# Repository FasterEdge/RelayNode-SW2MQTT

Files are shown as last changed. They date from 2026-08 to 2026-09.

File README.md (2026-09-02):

<div align="center">
  
  <h2>RelayNode-SW2MQTT</h2>
  <h3>四路隔离开关输入转 MQTT 节点</h3>
</div>

### 一、项目简介

- **用途**: 将四路干接点或开关输入转换为 Wi-Fi MQTT 状态消息，适用于边缘设备和工业开关量接入。
- **硬件工程**: `hardware/sw2mqtt_main.eprj2` 为嘉立创 EDA 专业版工程，`BOM.md` 与 `BOM.txt` 提供物料信息。
- **固件位置**: `firmware/ESP8266/platformio_ide/` 包含 ESP-12F 的 PlatformIO Arduino 固件；`firmware/README.md` 提供固件操作说明。

### 二、硬件设计

- **主控与网络**: 使用 ESP8266 ESP-12F Wi-Fi 模组。
- **输入接口**: 四路输入通过 PC817 光耦隔离，分别连接 GPIO14、GPIO12、GPIO13 和 GPIO4；光耦集电极侧使用 10KΩ 上拉。
- **USB 与烧录**: 板载 CH340X USB-UART 和 USB-C 接口，用于供电、串口烧录及调试。
- **电源**: USB-C 5V 经 AMS1117-3.3 转换为 3.3V；板载红色电源指示灯。
- **控制与状态**: SW1 将 RST 接地实现复位；GPIO2 驱动低电平有效的蓝色状态灯。
- **PCB 状态**: BOM 文档记录该设计为约 83.8 × 48.0 mm 的双层板，34 个元件、126 个焊盘和 29 个网络，最终 PCB DRC 为 0 错误、0 警告。

### 三、固件功能

- **输入采集**: 输入为低电平有效，默认防抖时间为 30 ms；状态变化后发布对应的 `0` 或 `1`。
- **设备标识**: 设备 ID 使用 `sw2mqtt-<chip-id>`，主题基路径为 `<FE_MQTT_TOPIC_PREFIX>/<device-id>`。
- **输入主题**: `input/1` 至 `input/4` 发布开关状态，并由 `FE_MQTT_RETAIN_INPUTS` 控制保留消息。
- **可用性主题**: `availability` 使用保留的 `online` / `offline` 消息，其中 `offline` 由 MQTT LWT 提供。
- **心跳主题**: `state` 周期发布包含运行时间、Wi-Fi RSSI 和 IP 地址的 JSON 心跳，模板默认周期为 60 秒。
- **连接维护**: Wi-Fi 未连接时每 15 秒重试，MQTT 未连接时每 5 秒重试；MQTT 连接成功时状态灯常亮，断开时闪烁。

### 四、配置与构建

- **构建环境**: PlatformIO 默认环境为 `esp12f`，使用 `espressif8266` 平台、`esp12e` 板级配置和 Arduino 框架。
- **依赖**: MQTT 客户端使用 `knolleary/PubSubClient@^2.8`，并启用 Arduino lwIP2 低内存构建标志。
- **串口参数**: 监视器波特率为 115200，上传速率为 460800。
- **配置文件**: 以 `include/config.example.h` 为模板配置 Wi-Fi、MQTT、主题前缀、防抖和心跳参数；不得提交真实密钥或生产凭据。

```bash
cd firmware/ESP8266/platformio_ide
pio run
pio run -t upload
pio device monitor
```

- **首次烧录**: 如开发板不能自动控制启动模式，按住 GPIO0 为低电平、触发 RESET 后再释放 GPIO0，手动进入 ESP8266 bootloader。

### 五、目录说明

- **`hardware/sw2mqtt_main.eprj2`**: 嘉立创 EDA 专业版硬件工程。
- **`BOM.md` / `BOM.txt`**: 物料、网络连接和生产验证信息。
- **`firmware/README.md`**: 固件功能、主题和烧录步骤。
- **`firmware/ESP8266/platformio_ide/`**: PlatformIO 工程、配置模板和 ESP8266 源码。

### 六、许可证

- **许可协议**: 根目录 `LICENSE` 为 Apache License 2.0。
- **凭据提醒**: 许可证不改变部署凭据的保密要求；发布、共享或提交前应确认配置中不包含真实 Wi-Fi 或 MQTT 密钥。

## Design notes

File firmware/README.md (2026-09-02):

# RelayNode-SW2MQTT firmware

## Directory

- `ESP8266/platformio_ide/`: ESP-12F firmware for VS Code + PlatformIO, Arduino framework.

## Features

- Reads the four optocoupler outputs on GPIO14, GPIO12, GPIO13 and GPIO4.
- Active-low input interpretation and 30 ms debounce.
- Publishes each state to MQTT using retained `0`/`1` payloads.
- MQTT availability/LWT (`online`/`offline`) and periodic JSON heartbeat.
- Uses the onboard GPIO2 status LED: on while MQTT is connected, blinking otherwise.

## Configure, build and flash

1. Edit `ESP8266/platformio_ide/include/config.h` with Wi-Fi and MQTT values. `config.example.h` is the template.
2. Connect USB-C. The onboard CH340X provides the serial flashing connection.
3. Put ESP8266 into bootloader mode if required by the board: hold GPIO0 low, pulse RESET, then release GPIO0.
4. Run:

```bash
cd ESP8266/platformio_ide
pio run
pio run -t upload
pio device monitor
```

MQTT topics use `<FE_MQTT_TOPIC_PREFIX>/<chip-id>/`:

- `availability`: `online`/`offline`
- `input/1` ... `input/4`: retained `0` or `1`
- `state`: heartbeat JSON containing uptime, RSSI and IP

> The hardware currently exposes RESET but may not provide automatic DTR/RTS boot control. Manual GPIO0 boot mode can therefore be necessary for the first flash.

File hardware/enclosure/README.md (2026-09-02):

# RelayNode-SW2MQTT 外壳

3D 打印外壳，覆盖 `sw2mqtt_main` PCB（83.8 × 48.0 mm）。

> 来源：嘉立创 EDA 工程 `sw2mqtt_main.eprj2` 实测板框（3300 × 1890 mil）。
> 风格：方形盒式上下盖，USB-C 从短边出线，JP1 排针从顶板穿出。
> 主要特点：**容纳 ESP-12F 模组（16 mm 高）的较高外壳（总高 ~24 mm）**。

## 目录结构

```
enclosure/
├── blender/                  # Blender 源文件
│   ├── enclosure.blend       # 主文件, PCB+34 元件占位 + 上下盖
│   └── enclosure.blend1      # Blender 自动生成
├── stl/
│   ├── top.stl               # 上盖 STL (748 三角面, 37 KB)
│   └── bottom.stl            # 底座 STL (340 三角面, 17 KB)
├── _shot_full.png             # Blender 视图截图(全场景)
├── _shot_shell.png           # 仅外壳视图截图
└── README.md
```

## 几何参数

### 整体

| 维度 | 数值 |
|---|---|
| 外尺寸（X×Y×Z） | 89.8 × 54.0 × 24.0 mm |
| 壁厚 | 2.0 mm |
| 板尺寸 | 83.8 × 48.0 mm（双层板，1.6 mm 厚） |
| 板上空间（内腔高度） | 20.2 mm（容纳 ESP-12F 模组） |
| 板下间隙 | 1.3 mm |

### 上盖（`top.stl`）

- **USB-C 通孔**：7.0 × 4.6 mm，位于 -X 短边壁（对准 J1 @ x=−36.3, y=−10.0）
  - y 范围 −13.5 至 −6.5（宽 7 mm，对准 J1 y=−10.0 中心）
  - z 范围 0.8 至 5.4（贯穿短边壁厚）—— Type-C 头从短边壁底部 4.6 mm 高开口露出
  - 短边壁只保留顶部 2 mm（z 5.4–7.4）作结构件
- **JP1 排针长槽**：x[29.0, 33.0]（宽 **4.0 mm**），y[−8.0, 13.0]（长 21 mm，覆盖 8 针 @ 2.54 mm 间距），z 贯穿整个上盖高度（0.8 → 23.0）让立式排针（高 5 mm）露在空腔内
- **SW1 复位键**：顶板开 6 × 6 mm 孔，内加**按压延长杆**（3 × 3 × 18.4 mm，x[−11.2,−8.2] y[−18.9,−15.9]，从按键顶 z=5.3 延伸到壳外 z=23.7 凸出 0.7 mm）——可从顶部直接按压复位
- **4 处卡扣凸耳**：+Y/−Y 外壁（y=±27.0）内侧 z 0.4–0.7 局部内凸 0.4 mm

### 底座（`bottom.stl`）

- 开口朝上，PCB 嵌入槽 85.8 × 50.0 × 1.3 mm（板 + 1 mm 单边间隙）
- **4 处滑动凹槽**：+Y/−Y 外壁（y=±27.0）内侧 z 0.4–0.8 局部内凹 0.4 mm，与上盖凸耳配合（y=±26.6–27.0 完全嵌合）

### 卡扣原理

滑动卡扣（snap-fit）：上盖从顶部压下，**凸耳（y=±26.6–27.0 内凸）沿底座凹槽（y=±26.6–27.0 内凹）滑入嵌合**，靠材料弹性 + 0.4 mm 过盈摩擦固定。

> **暗病修复记录（2025-02）**：
> 1. 卡扣位置错误（原放在 y=±10，而本壳外壁在 y=±27，卡扣悬浮在内腔且可能顶到 PCB）→ 已移到外壁 y=±26.6–27.0；
> 2. 凸耳方向错误（外凸与凹槽内凹方向相反无法嵌合）→ 已改为内凸同向嵌合；
> 3. SW1 复位键顶板孔原距按键 15.7 mm 无法按压 → 已加按压延长杆至壳外 0.7 mm；
> 4. JP1 槽原宽 2.6 mm 过窄 → 加宽至 4.0 mm。

## 元件位置（Blender 单位 mm，板中心 = 原点）

| 代号 | 名称 | 位置 (x, y) | 高度 (mm) | 外壳开孔 |
|---|---|---|---|---|
| U1 | ESP-12F 模组 | (−5.8, −2.7) | 16 | 无（内腔容纳） |
| J1 | USB-C 16P | (−36.3, −10.0) | 3.2 | 短边壁通孔 |
| JP1 | 1×8 排针立式 | (+31.0, +2.7) | 5.0 | 顶板长槽 |
| SW1 | 复位按键 | (−9.7, −16.4) | 4.5 | 顶板 6×6 mm 孔 |
| U2 | CH340X MSOP-10 | (−23.6, −10.0) | 1.0 | 无 |
| U3 | AMS1117-3.3 | (−24.9, −9.0) | 1.6 | 无 |
| U4-U7 | PC817×4 光耦 | (+17.0, −12.6 / −2.4 / +7.8 / +17.9) | 4.0 | 无 |
| R1-R16, C1-C6, D1, D2 | 0603 被动元件 | — | 0.6 | 无 |

## 打印参数建议

| 参数 | 数值 |
|---|---|
| 材料 | PLA / PETG |
| 层高 | 0.2 mm |
| 壁（Wall） | ≥ 2 条（0.4 mm 喷嘴）或 4 条（0.8 mm） |
| 填充（Infill） | 20 % |
| 顶/底层（Top/Bottom） | ≥ 4 层 |
| 支撑 | 仅外壳 **不需要**支撑（顶面朝上/底面朝上打印，悬垂面已被验证不存在） |
| 打印方向 | 上盖**顶面朝上**；底座**顶面（开口）朝上** |
| 水平扩展（Horizontal Expansion） | −0.05 mm（凹槽配合更顺滑） |

## 关键设计验证

| 检查项 | 结果 |
|---|---|
| 上下盖 mesh 水密（非流形 / 边界） | ✅ 0 / 0 |
| USB-C 通孔位置对准 J1 | ✅ |
| JP1 长槽覆盖 8 针位 | ✅ |
| SW1 复位键孔对准 SW1 + 延长杆 | ✅ 杆凸出顶面 0.7 mm 可按压 |
| ESP-12F 顶部 (z=16.8) vs 内腔顶 (z=21.0) | ✅ 余量 4.2 mm |
| 元件最高点（ESP 16.8）vs 内腔顶（21.0） | ✅ 余量 4.2 mm |
| STL 文件有效（头校验通过） | ✅ bottom 340 三角 / top 748 三角 |

## 嘉立创 EDA 协作工作流

```
Blender x = (jlc_x_mil − 1730) × 0.0254
Blender y = −(jlc_y_mil − 1505) × 0.0254
Blender z = 0.8 + ½ × 元件高度（板上表面参考）
```

板中心对齐原点（0, 0, 0），X 轴为板长方向（83.8 mm），USB-C 在 -X 短边。

如需从 EDA 重新同步 PCB 元件位置，编辑 `enclosure.blend` 中 `PCB_Reference` 集合的子对象尺寸/位置即可。

## 后续可优化项

- [ ] 加 PCB 定位柱（底部 2 定位销防止板晃动）
- [ ] LED D1（红）/ D2（蓝）位置在顶板或侧壁开小透光孔
- [ ] JP1 顶板外加可拆卸挡板（防尘）
- [ ] 顶部丝印（项目名 / 版本）

---

维护：硬件外壳与 PCB 同步更新。任何 PCB 修改后应重新核对 STL 关键尺寸（板框、端子位置、USB-C 位置、ESP 高度）。

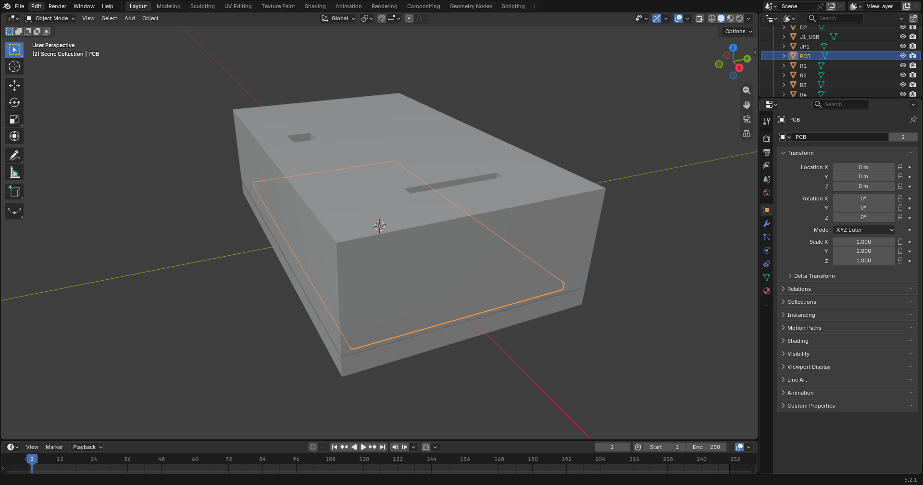
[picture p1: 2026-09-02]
hardware/enclosure/_shot_full.png

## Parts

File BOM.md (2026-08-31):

# RelayNode - SW2MQTT BOM

**开关转 MQTT 信号转换卡**（Switch → MQTT converter）· 嘉立创 EDA 专业版

## 设计要点

- 主控 **ESP8266 ESP-12F**（WiFi，FasterEdge MCU-ESP8266 固件，MQTTAbility）
- **4 路干接点/开关输入**，光耦 PC817 隔离
- 板载 **CH340X** USB-UART，USB-C 直插烧录/调试
- AMS1117-3.3 LDO，USB-C 5V → 3.3V
- D1 红色电源指示灯（3V3）、D2 蓝色状态指示灯（IO2）
- SW1 复位按键（RST↔GND），EN/IO0 上拉、IO15 下拉

## BOM 明细（LCSC 料号，最终确认）

| # | 位号 | 器件 | 型号 | LCSC | 数量 | 封装 |
|---|---|---|---|---|---|---|
| 1 | U1 | WiFi 模组 | ESP-12F | C19949064 | 1 | 模组 16×24mm |
| 2 | U2 | USB-UART | CH340X | C3035748 | 1 | MSOP-10 |
| 3 | U3 | LDO | AMS1117-3.3 | C6186 | 1 | SOT-223 |
| 4 | U4-U7 | 光耦 | PC817X1NSZ0F | C9900007695 | 4 | DIP-4 |
| 5 | J1 | USB-C 母座（16P 含 D+/D-） | TYPE-C-31-M-12 | C165948 | 1 | TYPE-C-SMD |
| 6 | JP1 | 开关输入端子 | 排母 1×8 2.54mm | C9900015386 | 1 | HDR-TH 2.54 |
| 7 | SW1 | 复位按键 | 轻触 2 脚 | C71845 | 1 | THT |
| 8 | D1 | LED 红色 | 0603 红色 | C9900005314 | 1 | 0603 |
| 9 | D2 | LED 蓝色（状态灯 IO2） | 0603 蓝色 | C9900013126 | 1 | 0603 |
| 10 | R1-R4,R11-R14 | 电阻 10KΩ（上拉/配置） | 0603WAF1002T5E | C25804 | 8 | 0603 |
| 11 | R5,R6 | 电阻 470Ω（LED 限流） | 0603WAF4700T5E | C23179 | 2 | 0603 |
| 12 | R7-R10 | 电阻 1KΩ（光耦阳极限流） | 0603WAF1001T5E | C21190 | 4 | 0603 |
| 13 | R15,R16 | 电阻 5.1KΩ（USB-C CC 下拉） | 0603WAF5101T5E | C23186 | 2 | 0603 |
| 14 | C1 | 电容 10µF（5V 输入） | CL10A106KP8NNNC | C19702 | 1 | 0603 |
| 15 | C2-C6 | 电容 100nF（去耦） | CC0603KRX7R9BB104 | C14663 | 5 | 0603 |

## 网络连接概要

- **电源**：J1(5V) → C1/C3 → U3(AMS1117-3.3) → 3V3 → U1/U2/C2/C4/C5
- **烧录**：J1 DP/DN → U2(UD+/UD-) → U2 TXD/RXD → U1 RXD/TXD（交叉）
- **开关输入**：JP1 IN1-4 → PC817 阴极；阳极经 1K→3V3；集电极 10K 上拉→U1 IO14/12/13/4
- **配置**：EN/IO0 上拉 10K，IO15 下拉 10K，RST↔SW1↔GND

## 生产与验证状态

- 原理图：34 个元件，普通模式 DRC 通过；严格模式会因桥 API 无法读取库引脚元数据而返回 false，不影响已生成且一致的 PCB 网表。
- PCB：34 个元件、126 个焊盘、29 个网络，29/29 网络已布通。
- 最终 PCB DRC：0 错误、0 警告；20mil 元件间距检查 561 对，0 违规。
- 布线：289 条走线，统一 10mil；20 个过孔；顶层和底层各 1 个 GND 铺铜。
- 板框约 3300×1890mil（约 83.8×48.0mm），2 层板。
- 丝印位号由 PCB Attribute 图元承载（顶层丝印层 3，共 103 项）；MCP 的 `pcb_get_silkscreens` 只统计 PrimitiveString，因此会误报 0。
- 设计健康报告中的“29 个载流警告”是 MCP 宽度统计缺陷：报告错误读取为 0mil；直接读取 PCB 图元已确认全部 289 条走线均为 10mil，且 GND 有双层铺铜。

## 备注

- 电阻阻值均按实际器件核对（10K=0603WAF1002T5E，470Ω=0603WAF4700T5E，1K=0603WAF1001T5E，5.1K=0603WAF5101T5E），避免早期误选的 5.1Ω/4.7K 错误。
- 光耦用于开关输入隔离，适合工业干接点场景。
- 工程中的生产板为 **Board1（Schematic1 + PCB1）**；`Legacy_Empty_DoNotUse` 是 EDA 自动生成的空原理图占位板，不用于生产，也不要删除，以免触发文档级联操作。

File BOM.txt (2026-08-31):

RelayNode - SW2MQTT BOM（以当前嘉立创 EDA 工程为准）

项目功能：ESP8266 四路隔离开关输入 → MQTT；USB-C 供电与 CH340X 串口烧录
默认装配：全部器件安装

序号	位号	数量	类别/用途	参数或型号	制造商料号/选型	LCSC	封装
1	U1	1	WiFi MCU 模组	ESP8266 ESP-12F	ESP-12F	C19949064	ESP-12F 模组 16×24mm
2	U2	1	USB-UART	CH340X	CH340X	C3035748	MSOP-10
3	U3	1	3.3V LDO	AMS1117-3.3	AMS1117-3.3	C6186	SOT-223
4	U4-U7	4	输入隔离光耦	PC817X1NSZ0F	PC817X1NSZ0F	C9900007695	DIP-4
5	J1	1	USB-C 母座	TYPE-C-31-M-12	TYPE-C-31-M-12	C165948	TYPE-C-SMD 16P
6	JP1	1	四路开关/GND 输入端子	排母 1×8，2.54mm	1×8P 2.54mm 排母	C9900015386	HDR-TH 1×8 2.54mm
7	SW1	1	复位按键	轻触按键，常开，2脚	THT 轻触按键	C71845	THT 2P
8	D1	1	电源指示灯	红色 LED	0603 红色 LED	C9900005314	0603
9	D2	1	状态指示灯	蓝色 LED	0603 蓝色 LED	C9900013126	0603
10	R1-R4,R11-R14	8	上拉/启动配置电阻	10kΩ，1%	0603WAF1002T5E	C25804	0603
11	R5,R6	2	LED 限流电阻	470Ω，1%	0603WAF4700T5E	C23179	0603
12	R7-R10	4	光耦输入限流电阻	1kΩ，1%	0603WAF1001T5E	C21190	0603
13	R15,R16	2	USB-C CC 下拉电阻	5.1kΩ，1%	0603WAF5101T5E	C23186	0603
14	C1	1	5V 输入滤波电容	10µF，10V，X5R/X7R	CL10A106KP8NNNC	C19702	0603
15	C2-C6	5	电源去耦电容	100nF，50V，X7R	CC0603KRX7R9BB104	C14663	0603

数量汇总：
- IC/模组：U1-U7，共 7 个
- 连接器/开关：J1、JP1、SW1，共 3 个
- LED：D1-D2，共 2 个
- 电阻：R1-R16，共 16 个
- 电容：C1-C6，共 6 个
- 总装配器件数：34 个

采购与装配说明：
- ESP-12F 模组需要在天线端保持禁布、禁铜区域，装配方向以 PCB 丝印为准。
- U4-U7 四只 PC817 必须保持同一型号和引脚方向，1脚标记按丝印安装。
- R15/R16 必须为 5.1kΩ，不得误装成 5.1Ω；它们是 USB-C CC1/CC2 的 Rd 下拉。
- R7-R10 为 1kΩ 光耦输入限流；R5/R6 为 470Ω LED 限流；不要混料。
- C1 建议耐压不低于 10V；C2-C6 为 100nF 去耦，靠近对应芯片电源脚安装。
- JP1 为 1×8、2.54mm 通孔排母；若改用接线端子，必须复核孔距、孔径和外形尺寸。
- C990000xxxx 类料号可能属于扩展/定制库，上单前应在立创商城再次确认可采购性；缺货时只能使用封装、电气参数和引脚定义完全一致的替代料。

网络功能核对：
- USB-C VBUS → 输入滤波 → AMS1117-3.3 → 3V3。
- USB D+/D− → CH340X；CH340X TXD/RXD → ESP-12F RXD/TXD。
- 四路输入经 PC817 隔离后进入 ESP8266 GPIO。
- SW1 为 RST 到 GND 的复位按键。

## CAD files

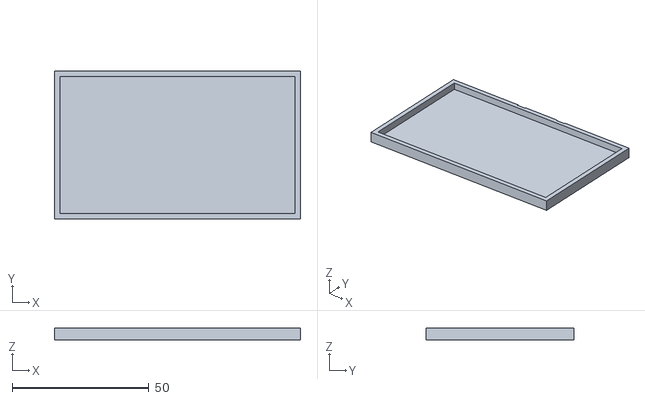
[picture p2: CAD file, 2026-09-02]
hardware/enclosure/stl/bottom.stl
89.8 x 54.0 x 4.40

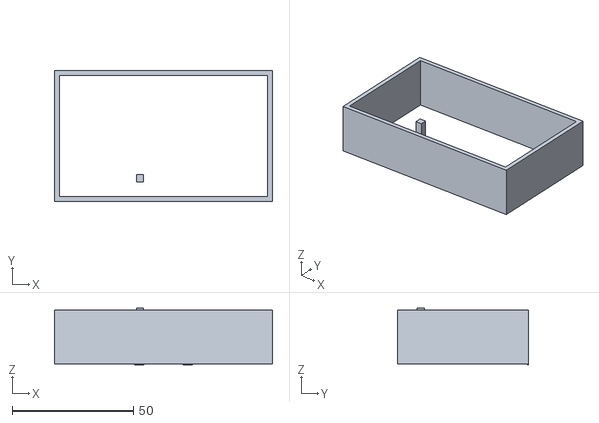
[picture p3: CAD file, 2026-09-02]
hardware/enclosure/stl/top.stl
89.8 x 54.0 x 23.3

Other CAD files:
hardware/enclosure/blender/enclosure.blend

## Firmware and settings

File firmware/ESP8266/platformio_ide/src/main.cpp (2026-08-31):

// FasterEdge 开源项目 · https://github.com/FasterEdge · https://gitee.com/FasterEdge
#include <Arduino.h>
#include <ESP8266WiFi.h>
#include <PubSubClient.h>
#include "config.h"

namespace {
constexpr uint8_t kInputCount = 4;
// Hardware net order: IN1..IN4 -> ESP8266 GPIO14, GPIO12, GPIO13, GPIO4.
constexpr uint8_t kInputPins[kInputCount] = {14, 12, 13, 4};
constexpr uint8_t kStatusLedPin = 2;  // D2, active-low on the board.

WiFiClient wifiClient;
PubSubClient mqtt(wifiClient);
String deviceId;
String topicBase;
bool stableState[kInputCount] = {false, false, false, false};
bool sampledState[kInputCount] = {false, false, false, false};
uint32_t changedAt[kInputCount] = {0, 0, 0, 0};
uint32_t lastWifiAttempt = 0;
uint32_t lastMqttAttempt = 0;
uint32_t lastHeartbeat = 0;

bool readActive(uint8_t index) {
  // PC817 collector outputs have 10k pull-ups; closed/active input pulls low.
  return digitalRead(kInputPins[index]) == LOW;
}

String inputTopic(uint8_t index) {
  return topicBase + "/input/" + String(index + 1);
}

void publishInput(uint8_t index, bool force = false) {
  if (!mqtt.connected() && !force) return;
  const char *payload = stableState[index] ? "1" : "0";
  mqtt.publish(inputTopic(index).c_str(), payload, FE_MQTT_RETAIN_INPUTS);
}

void publishAllInputs() {
  for (uint8_t i = 0; i < kInputCount; ++i) publishInput(i);
}

void beginWifi() {
  if (strlen(FE_WIFI_SSID) == 0) return;
  WiFi.persistent(false);
  WiFi.mode(WIFI_STA);
  WiFi.hostname(deviceId);
  WiFi.begin(FE_WIFI_SSID, FE_WIFI_PASSWORD);
  lastWifiAttempt = millis();
}

void maintainWifi() {
  if (strlen(FE_WIFI_SSID) == 0 || WiFi.status() == WL_CONNECTED) return;
  if (millis() - lastWifiAttempt >= 15000UL) beginWifi();
}

void maintainMqtt() {
  if (WiFi.status() != WL_CONNECTED || mqtt.connected()) return;
  if (millis() - lastMqttAttempt < 5000UL) return;
  lastMqttAttempt = millis();

  const String availability = topicBase + "/availability";
  bool ok;
  if (strlen(FE_MQTT_USERNAME) != 0) {
    ok = mqtt.connect(deviceId.c_str(), FE_MQTT_USERNAME, FE_MQTT_PASSWORD,
                      availability.c_str(), 1, true, "offline");
  } else {
    ok = mqtt.connect(deviceId.c_str(), availability.c_str(), 1, true, "offline");
  }
  if (!ok) return;

  mqtt.publish(availability.c_str(), "online", true);
  publishAllInputs();
}

void scanInputs() {
  const uint32_t now = millis();
  for (uint8_t i = 0; i < kInputCount; ++i) {
    const bool current = readActive(i);
    if (current != sampledState[i]) {
      sampledState[i] = current;
      changedAt[i] = now;
    }
    if (sampledState[i] != stableState[i] && now - changedAt[i] >= FE_DEBOUNCE_MS) {
      stableState[i] = sampledState[i];
      publishInput(i);
      Serial.printf("SW%u=%u\n", i + 1, stableState[i] ? 1 : 0);
    }
  }
}

void heartbeat() {
  if (!mqtt.connected() || millis() - lastHeartbeat < FE_HEARTBEAT_MS) return;
  lastHeartbeat = millis();
  const String topic = topicBase + "/state";
  const String payload = String("{\"uptime_ms\":") + millis() +
                         ",\"rssi\":" + WiFi.RSSI() +
                         ",\"ip\":\"" + WiFi.localIP().toString() + "\"}";
  mqtt.publish(topic.c_str(), payload.c_str(), false);
}
}  // namespace

void setup() {
  Serial.begin(115200);
  Serial.println();
  Serial.println(F("RelayNode-SW2MQTT ESP8266 firmware"));

  pinMode(kStatusLedPin, OUTPUT);
  digitalWrite(kStatusLedPin, HIGH);
  for (uint8_t i = 0; i < kInputCount; ++i) {
    pinMode(kInputPins[i], INPUT_PULLUP);
    sampledState[i] = stableState[i] = readActive(i);
    changedAt[i] = millis();
  }

  deviceId = "sw2mqtt-" + String(ESP.getChipId(), HEX);
  topicBase = String(FE_MQTT_TOPIC_PREFIX) + "/" + deviceId;
  mqtt.setServer(FE_MQTT_HOST, FE_MQTT_PORT);
  mqtt.setBufferSize(384);
  beginWifi();
}

void loop() {
  maintainWifi();
  maintainMqtt();
  if (mqtt.connected()) mqtt.loop();
  scanInputs();
  heartbeat();
  digitalWrite(kStatusLedPin, mqtt.connected() ? LOW : ((millis() / 500U) & 1U));
  delay(2);
}

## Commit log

2026-08-31 feat: add ESP8266 firmware — 4-channel optocoupler to MQTT
    - ESP12F PlatformIO/Arduino firmware: reads 4 optocoupler inputs (GPIO14/12/13/4)
    - Active-low with 30ms debounce, retained MQTT 0/1 payloads, LWT + heartbeat
    - config.example.h template; README with build/flash instructions
2026-08-31 docs: 源码注释中加入 FasterEdge 组织标识与 GitHub/Gitee 链接
2026-09-01 docs: 补齐中英文 README 文档
2026-09-01 docs: 源码注释补充 FasterEdge 组织标识（Github/Gitee 链接）
2026-09-02 chore: 目录整理 - software 重命名为 firmware，嘉立创 EDA 工程(.eprj2)移至 hardware/，同步更新 README
2026-09-02 Add 3D printed enclosure for RelayNode-SW2MQTT
    - 89.8x54.0x24.0mm square box, top + bottom shell
    - Wall thickness 2mm, snap-fit tabs (4x grooves on bottom, 4x lugs on top)
    - USB-C through-hole on -X short edge (9.4x3.5mm) aligned to J1
    - JP1 1x8 pinheader long slot on top (2.6mm wide, 21mm long, through
    entire shell height) - 立式排针直接在内腔内可见
    - SW1 reset button 6x6mm hole on top
    - Enclosure height 24mm accommodates ESP-12F module (16mm)
    - Enclosure dimensions derived from JLC EDA sw2mqtt_main project:
    PCB 83.82x48.01mm (3300x1890 mil)
    - Both shells watertight (0 non-manifold / 0 boundary)
    - STL exports validated: bottom.stl 348 tris, top.stl 1016 tris
    [bottom.stl, enclosure.blend, top.stl]
2026-09-02 Enlarge USB-C opening on top shell (more accessible)
    - USB-C slot widened from 4mm to 7mm in Y direction
    - Hole y range: -13.5 to -6.5mm (centered at y=-10, aligned to J1)
    - Shell still watertight (0 non-manifold / 0 boundary)
    - STL: top.stl 1080 triangles, hole geometry validated
    [enclosure.blend, top.stl]
2026-09-02 Extend USB-C opening: z range to 0.8-5.4 (full short wall)
    - USB-C hole z range extended from 1.0-4.5 to 0.8-5.4 (4.6mm tall)
    - Through entire short wall thickness, Type-C connector fully exposed
    - Short wall now has only top 2mm structural band (z 5.4-7.4)
    - STL: top.stl 908 triangles (45 KB)
    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
    [enclosure.blend, top.stl]
2026-09-02 Fix 4 design defects found in audit
    1. Snap-fit latches were at y=+/-10 but this shell's outer wall is
    y=+/-27 (board is 48mm wide) - latches floated in cavity and could
    hit the PCB. Moved to outer wall y=+/-26.6..27.0.
    2. Latch lugs were OUTER bumps vs INNER grooves (opposite directions,
    never engaged). Now INNER protrusions overlapping grooves.
    3. SW1 reset button: top-plate hole was 15.7mm above the button,
    unreachable. Added 3x3x18.4mm push-plunger extending to 0.7mm
    above shell top (z=23.7).
    4. JP1 slot was 2.6mm wide (too narrow for wiring); widened to 4.0mm.
    - Enclosure_Top rebuilt (380v/374f), Bottom rebuilt (172v/170f), both watertight 0/0
    - STL: top.stl 748 tris (ma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
    [bottom.stl, enclosure.blend, top.stl]
2026-09-04 docs: 新增 SECURITY.md 安全政策
    统一安全报告渠道 (GitHub Security Advisory + 邮件), 与
    FasterEdge 组织安全政策一致。避免未修复漏洞细节在公开
    渠道泄露。
2026-09-04 chore: 新增 .gitignore (PlatformIO/嵌入式固件产物)
2026-09-10 ci: 新增 PlatformIO 构建检查(编译仓库内全部 platformio 工程)
2026-09-10 ci: PlatformIO 构建跳过纯头文件工程(无源码不构建)
2026-09-10 ci: 修复 workflow 结尾判断(set -e 下 && 链非零导致必失败)
2026-10-23 ci(deps): extend dependabot coverage to every manifest
    新增 1 条 update 配置：github-actions@/
    这些清单此前没有任何 dependabot 条目，CVE 扫描完全覆盖不到。
